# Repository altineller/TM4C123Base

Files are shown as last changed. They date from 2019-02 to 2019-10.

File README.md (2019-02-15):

# TM4C123Base

## Reference Design using TM4C123GH6PM suitable for small robotics

This is a MCU board for using the ARM Cortex-M4 TM4C123GH6PM microcontroller in small robotics.

It is the same MCU as the TI TM4C123 Launchpad: http://www.ti.com/tool/EK-TM4C123GXL , except for all the pins are available, and the hibernate circuit works. It also has a backup battery enabling the RTC functions, hibernate and wake-up operations. It can turn on or off an external power supply.

The reason we developed this board is that the TM4C123GXL board does not fit well in small robots, and one can not take advantage of the hibernate functionality.

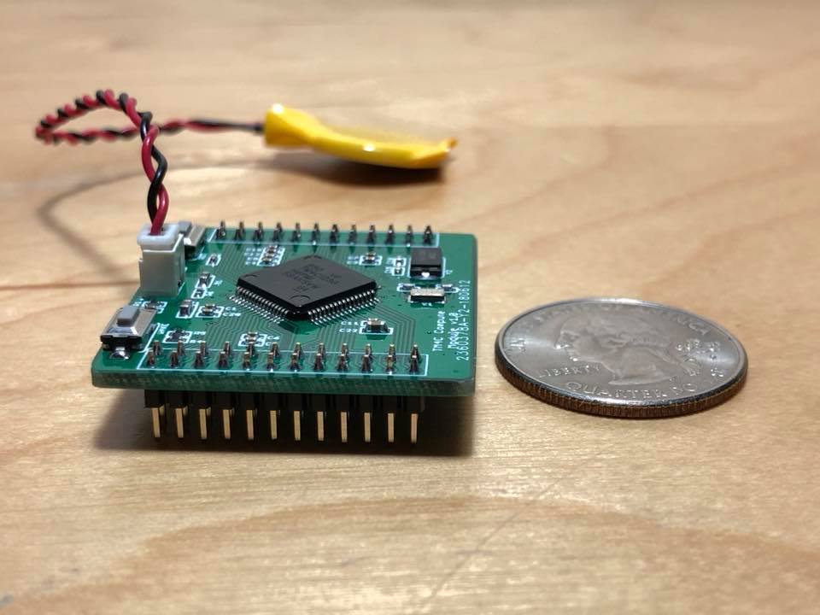
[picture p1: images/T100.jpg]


It can be programmed by using CCS, gcc-arm, or Energia, and it is thoroughly tested. To program it, you either need a TM4C123GXL board or an external debug probe like XDS110.

Although 402 size smd components are used, it is relatively easy to solder it with hand using a hot air station. The gerbers are produced so any board house can build them.

This board has been extensively tested, and also powers the robotics project at https://github.com/altineller/DuckiePilot

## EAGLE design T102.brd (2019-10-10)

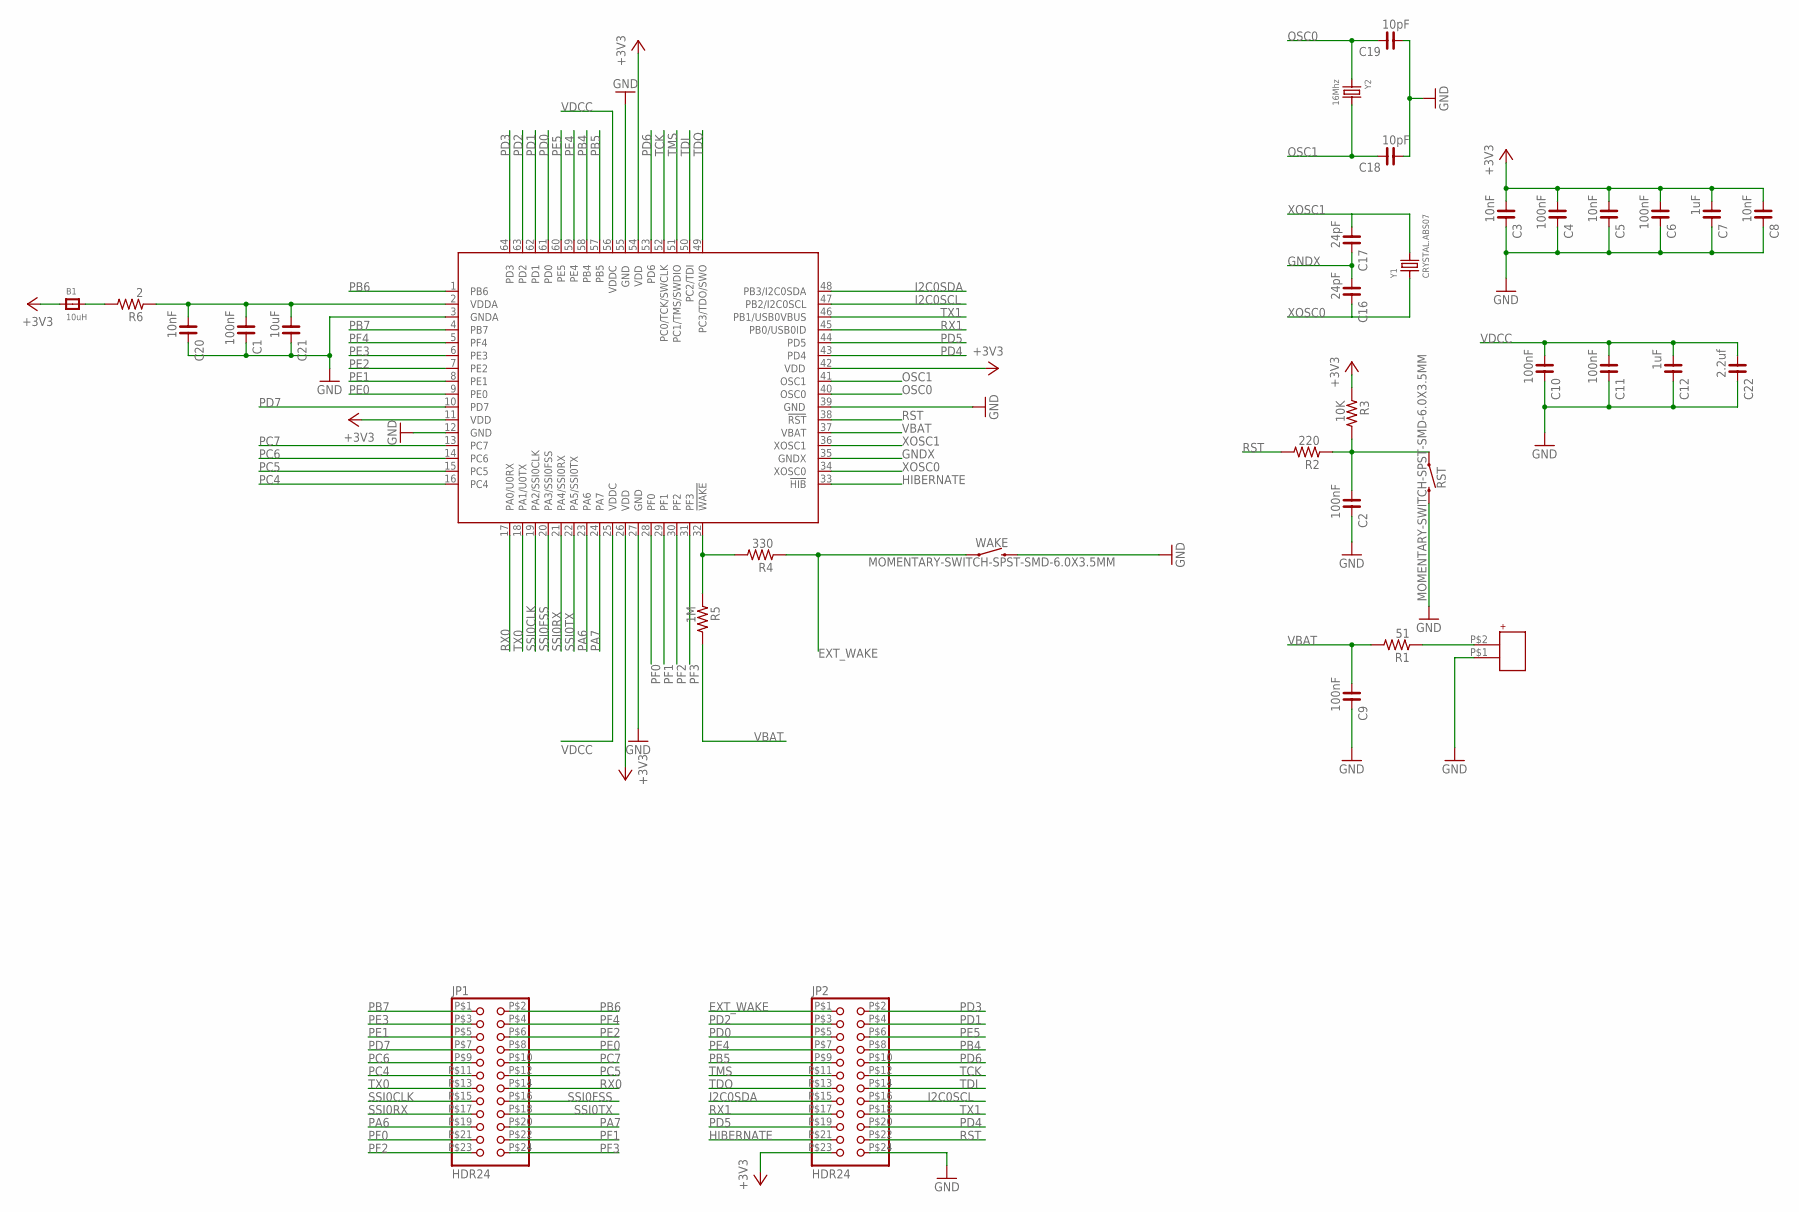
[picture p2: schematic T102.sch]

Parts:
B1: 10uH; _0603
C1, C2, C4, C6, C9, C10, C11: 100nF; C0402
C3, C5, C8, C20: 10nF; C0402
C7, C12: 1uF; C0402
C16, C17: 24pF; C0402
C18, C19: 10pF; C0402
C21: 10uF; C0603
C22: 2.2uf; C0603
IC1: TM4C123[7,G]XXPM; PM_S-PQFP-G64
JP1, JP2: HDR24
R1: 51; R0402
R2: 220; R0402
R3: 10K; R0402
R4: 330; R0402
R5: 1M; R0402
R6: 2; R0402
RST: MOMENTARY-SWITCH-SPST-SMD-6.0X3.5MM; TACTILE_SWITCH_SMD_6.0X3.5MM
U$1: JST-MICROBAT
WAKE: MOMENTARY-SWITCH-SPST-SMD-6.0X3.5MM; TACTILE_SWITCH_SMD_6.0X3.5MM
Y1: CRYSTAL.ABS07; ABS07
Y2: 16Mhz; 6X3.3MM

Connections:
+3V3: B1.1, C3.1, C4.1, C5.1, C6.1, C7.1, C8.1, IC1.11 (VDD), IC1.26 (VDD), IC1.42 (VDD), IC1.54 (VDD), JP2.P$23 (23), R3.1
EXT_WAKE: JP2.P$1 (1), R4.1, WAKE.1
GND: C1.2, C2.2, C3.2, C4.2, C5.2, C6.2, C7.2, C8.2, C9.2, C10.2, C11.2, C12.2, C18.1, C19.1, C20.2, C21.2, C22.2, IC1.3 (GNDA), IC1.12 (GND), IC1.27 (GND), IC1.39 (GND), IC1.55 (GND), JP2.P$24 (24), RST.2, U$1.P$1, WAKE.2
GNDX: C16.1, C17.2, IC1.35 (GNDX)
HIBERNATE: IC1.33 (!HIB), JP2.P$21 (21)
I2C0SCL: IC1.47 (PB2/I2C0SCL), JP2.P$16 (16)
I2C0SDA: IC1.48 (PB3/I2C0SDA), JP2.P$15 (15)
unnamed: R1.1, U$1.P$2
unnamed: C2.1, R2.1, R3.2, RST.1
unnamed: C1.1, C20.1, C21.1, IC1.2 (VDDA), R6.1
unnamed: B1.2, R6.2
N_WAKE: IC1.32 (!WAKE), R4.2, R5.1
OSC0: C19.2, IC1.40 (OSC0), Y2.1
OSC1: C18.2, IC1.41 (OSC1), Y2.2
PA6: IC1.23 (PA6), JP1.P$19 (19)
PA7: IC1.24 (PA7), JP1.P$20 (20)
PB4: IC1.58 (PB4), JP2.P$8 (8)
PB5: IC1.57 (PB5), JP2.P$9 (9)
PB6: IC1.1 (PB6), JP1.P$2 (2)
PB7: IC1.4 (PB7), JP1.P$1 (1)
PC4: IC1.16 (PC4), JP1.P$11 (11)
PC5: IC1.15 (PC5), JP1.P$12 (12)
PC6: IC1.14 (PC6), JP1.P$9 (9)
PC7: IC1.13 (PC7), JP1.P$10 (10)
PD0: IC1.61 (PD0), JP2.P$5 (5)
PD1: IC1.62 (PD1), JP2.P$4 (4)
PD2: IC1.63 (PD2), JP2.P$3 (3)
PD3: IC1.64 (PD3), JP2.P$2 (2)
PD4: IC1.43 (PD4), JP2.P$20 (20)
PD5: IC1.44 (PD5), JP2.P$19 (19)
PD6: IC1.53 (PD6), JP2.P$10 (10)
PD7: IC1.10 (PD7), JP1.P$7 (7)
PE0: IC1.9 (PE0), JP1.P$8 (8)
PE1: IC1.8 (PE1), JP1.P$5 (5)
PE2: IC1.7 (PE2), JP1.P$6 (6)
PE3: IC1.6 (PE3), JP1.P$3 (3)
PE4: IC1.59 (PE4), JP2.P$7 (7)
PE5: IC1.60 (PE5), JP2.P$6 (6)
PF0: IC1.28 (PF0), JP1.P$21 (21)
PF1: IC1.29 (PF1), JP1.P$22 (22)
PF2: IC1.30 (PF2), JP1.P$23 (23)
PF3: IC1.31 (PF3), JP1.P$24 (24)
PF4: IC1.5 (PF4), JP1.P$4 (4)
RST: IC1.38 (!RST), JP2.P$22 (22), R2.2
RX0: IC1.17 (PA0/U0RX), JP1.P$14 (14)
RX1: IC1.45 (PB0/USB0ID), JP2.P$17 (17)
SSI0CLK: IC1.19 (PA2/SSI0CLK), JP1.P$15 (15)
SSI0FSS: IC1.20 (PA3/SSI0FSS), JP1.P$16 (16)
SSI0RX: IC1.21 (PA4/SSI0RX), JP1.P$17 (17)
SSI0TX: IC1.22 (PA5/SSI0TX), JP1.P$18 (18)
TCK: IC1.52 (PC0/TCK/SWCLK), JP2.P$12 (12)
TDI: IC1.50 (PC2/TDI), JP2.P$14 (14)
TDO: IC1.49 (PC3/TDO/SWO), JP2.P$13 (13)
TMS: IC1.51 (PC1/TMS/SWDIO), JP2.P$11 (11)
TX0: IC1.18 (PA1/U0TX), JP1.P$13 (13)
TX1: IC1.46 (PB1/USB0VBUS), JP2.P$18 (18)
VBAT: C9.1, IC1.37 (VBAT), R1.2, R5.2
VDCC: C10.1, C11.1, C12.1, C22.1, IC1.25 (VDDC), IC1.56 (VDDC)
XOSC0: C16.2, IC1.34 (XOSC0), Y1.1
XOSC1: C17.1, IC1.36 (XOSC1), Y1.2

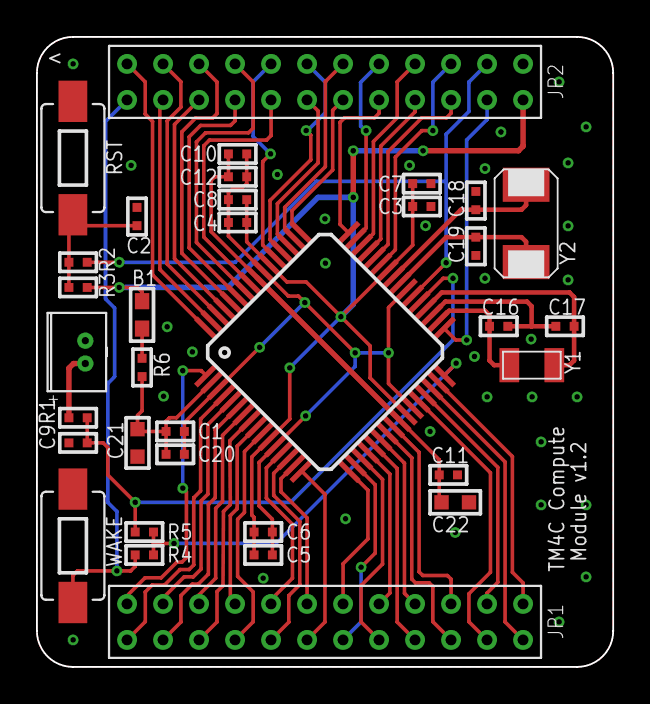
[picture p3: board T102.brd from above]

Board: 2 copper layers, 32.0 x 35.0 mm, 34 parts (0 on the bottom side), 60 nets.

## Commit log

2019-02-15 first commit
    added the brd and the sch
    [T101.brd, T101.sch]
2019-02-15 added gerber files
    [T101.GBL, T101.GBO, T101.GBP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]
2019-10-10 new version
    [T102.brd, T102.sch]

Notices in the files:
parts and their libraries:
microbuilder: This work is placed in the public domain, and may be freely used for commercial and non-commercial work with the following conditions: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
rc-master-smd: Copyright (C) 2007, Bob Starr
